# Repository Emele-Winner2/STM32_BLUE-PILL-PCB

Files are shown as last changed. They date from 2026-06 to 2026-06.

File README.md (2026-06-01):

# Custom STM32F103 "Blue Pill" Development Board 🚀

This repository contains the complete hardware design files for a custom, enhanced 4-layer redesign of the classic STM32F103 "Blue Pill" development board. Designed entirely in KiCad, this board optimizes signal integrity, power distribution, and clock stability compared to standard 2-layer commercial alternatives.

---

## 🛠️ Hardware Specifications & Features

* **MCU Core:** STM32F103C8T6 ARM Cortex-M3 microcontroller.
* **4-Layer Stackup:** Engineered with dedicated internal planes to maximize electromagnetic shielding and ensure pristine signal paths.
  * **Layer 1 (Top):** High-speed signaling (USB differential pairs), crystal oscillator tracking, and local component connections.
  * **Layer 2 (Internal):** Solid, unbroken **Ground (GND) Plane** for low-impedance return paths.
  * **Layer 3 (Internal):** **Power (PWR) Plane** for clean 5V power distribution.
  * **Layer 4 (Bottom):** General purpose I/O breakouts and non-critical low-speed routing.
* **USB Interface:** Native USB Full-Speed connection with hardware-matched series termination resistors and a proper 3.3V pull-up network for reliable host computer enumeration.
* **Dual Clock Architecture:** * High-Speed External (HSE): 8MHz main crystal with optimized, short symmetric routing.
  * Low-Speed External (LSE): 32.768kHz dedicated real-time clock (RTC) crystal.

---

## 📂 Repository Structure

```text
├── bluetooth_mcu.kicad_pro   # KiCad main project file
├── bluetooth_mcu.kicad_sch   # System schematic design
├── bluetooth_mcu.kicad_pcb   # 4-layer PCB layout design
└── README.md                 # Project documentation (this file)

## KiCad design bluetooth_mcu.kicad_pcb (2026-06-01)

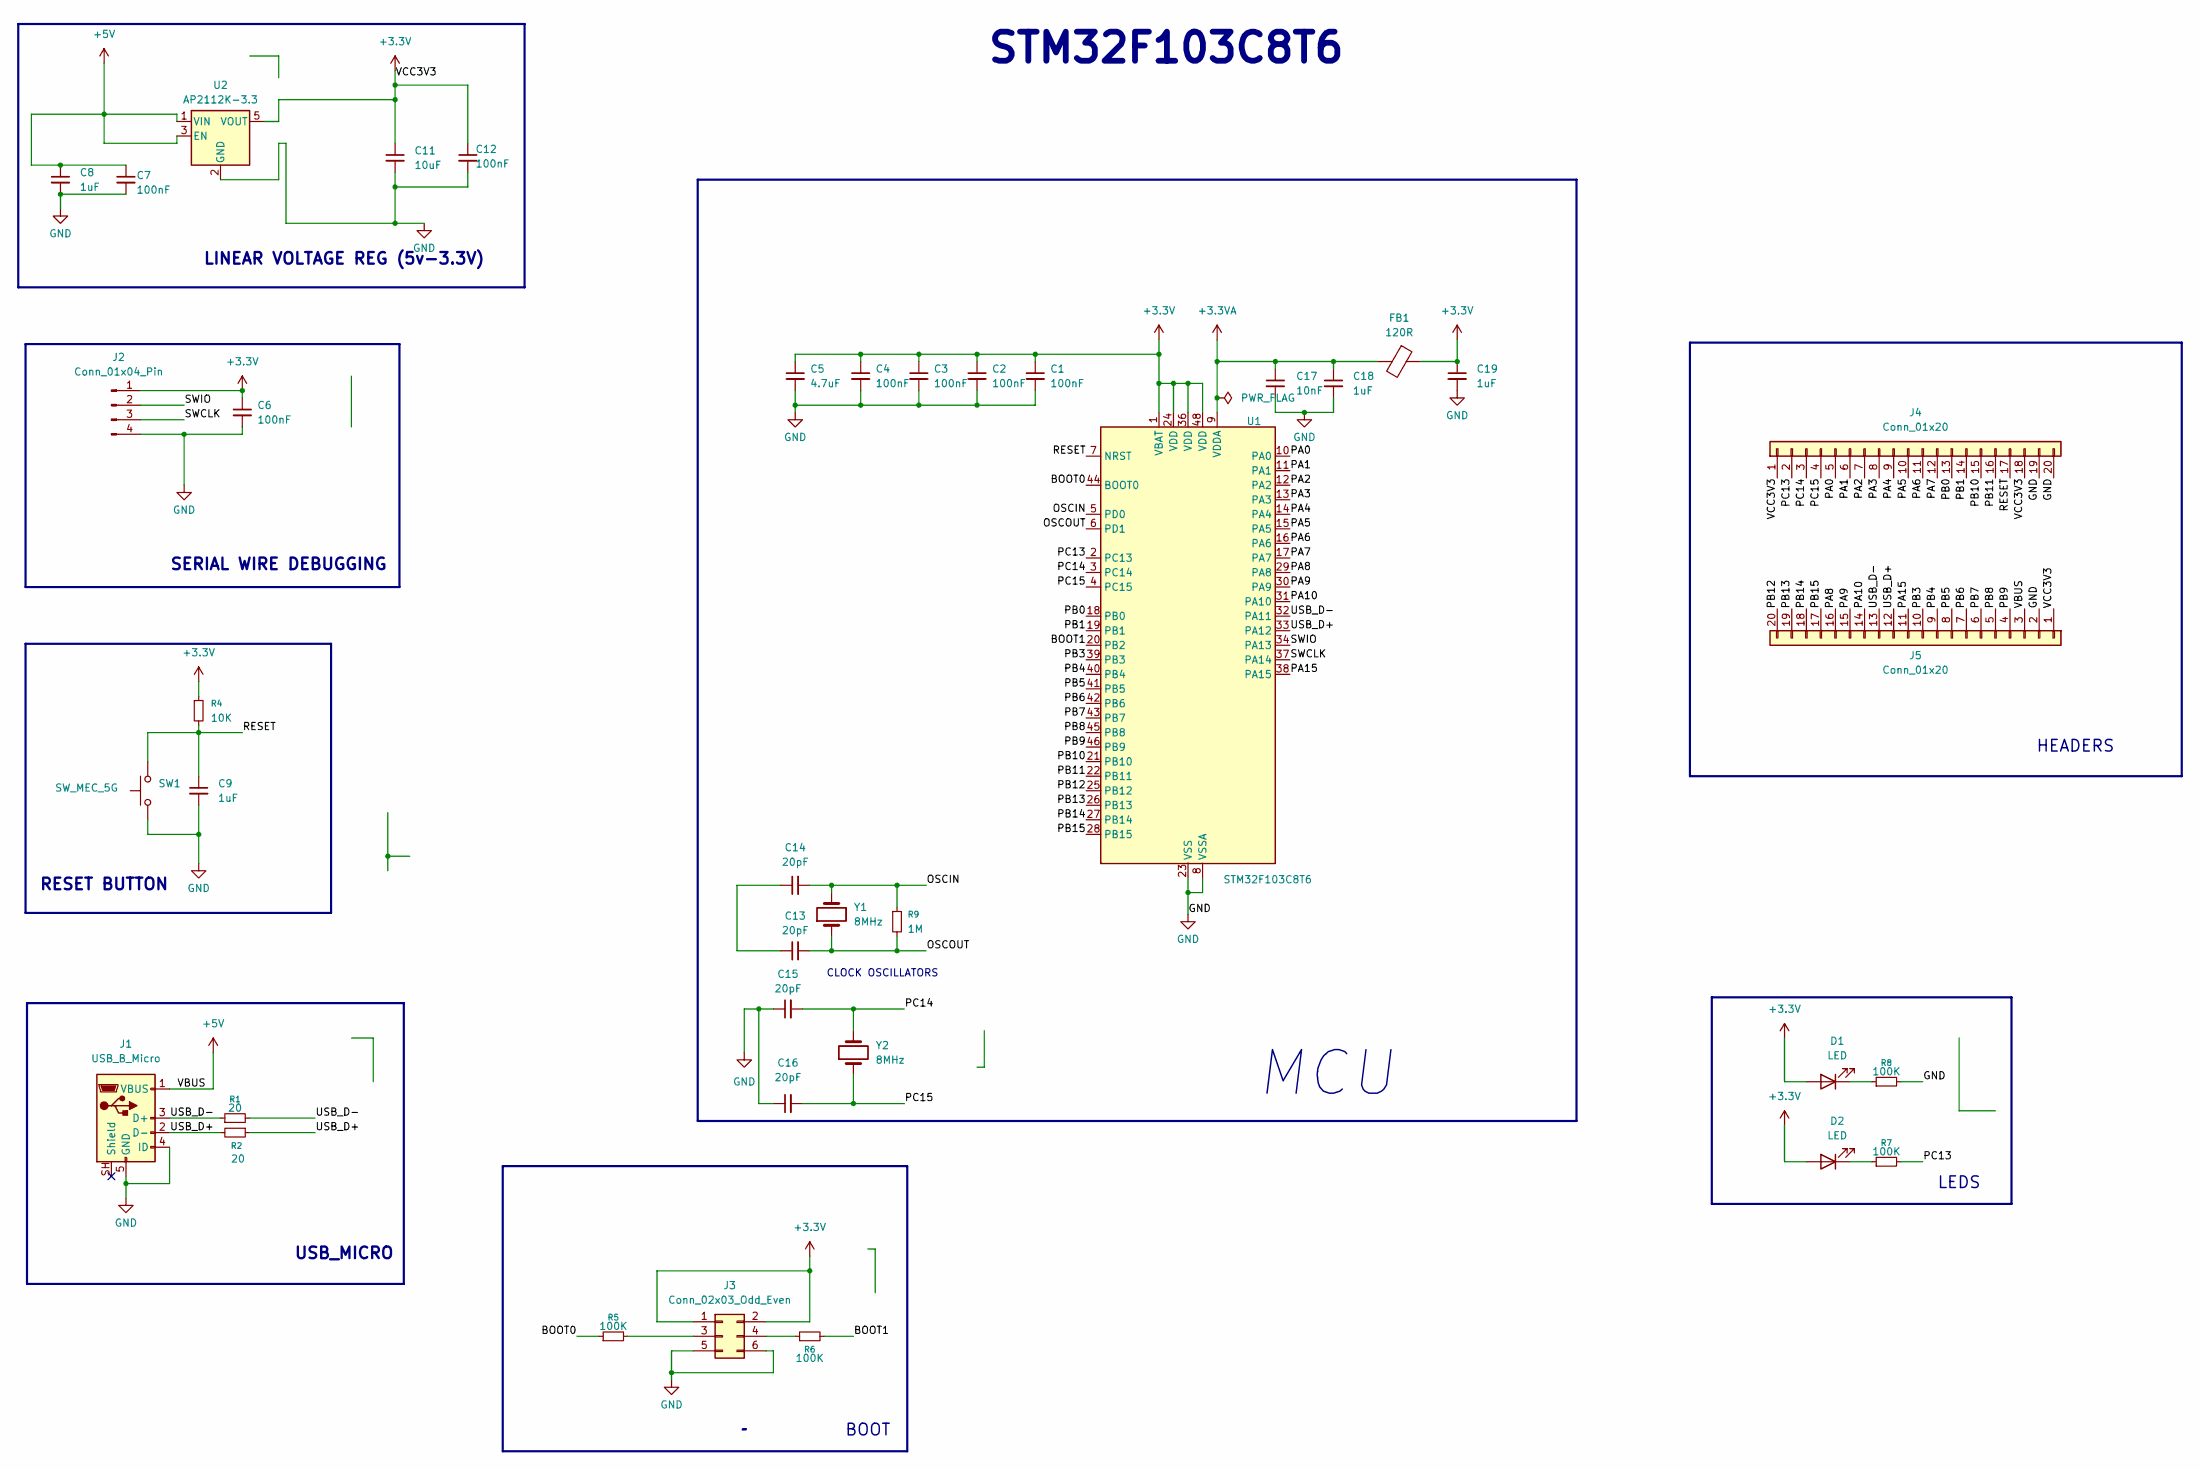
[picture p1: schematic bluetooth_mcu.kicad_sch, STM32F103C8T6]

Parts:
C1, C2, C3, C4, C6, C7, C12: 100nF; C_0603_1608Metric_Pad1.08x0.95mm_HandSolder
C5: 4.7uF; C_0603_1608Metric_Pad1.08x0.95mm_HandSolder
C8, C9, C18, C19: 1uF; C_0603_1608Metric_Pad1.08x0.95mm_HandSolder
C11: 10uF; C_0603_1608Metric_Pad1.08x0.95mm_HandSolder
C13, C14: 20pF; C_0402_1005Metric_Pad0.74x0.62mm_HandSolder
C15, C16: 20pF; C_0603_1608Metric_Pad1.08x0.95mm_HandSolder
C17: 10nF; C_0603_1608Metric_Pad1.08x0.95mm_HandSolder
D1, D2: LED; LED_0402_1005Metric_Pad0.77x0.64mm_HandSolder
FB1: 120R; R_0603_1608Metric
J1: USB_B_Micro; USB_Micro-B_Molex-105017-0001
J2: Conn_01x04_Pin; PinHeader_1x04_P2.54mm_Horizontal
J3: Conn_02x03_Odd_Even; PinHeader_2x03_P2.54mm_Vertical
J4, J5: Conn_01x20; PinHeader_1x20_P2.54mm_Vertical
R1, R2: 20; R_0603_1608Metric_Pad0.98x0.95mm_HandSolder
R4: 10K; R_0603_1608Metric_Pad0.98x0.95mm_HandSolder
R5, R6, R7, R8: 100K; R_0603_1608Metric_Pad0.98x0.95mm_HandSolder
R9: 1M; R_0603_1608Metric_Pad0.98x0.95mm_HandSolder
SW1: SW_MEC_5G; SW_PUSH_1P1T_6x3.5mm_H4.3_APEM_MJTP1243
U1: STM32F103C8T6; LQFP-48_7x7mm_P0.5mm
U2: AP2112K-3.3; SOT-23-5
Y1, Y2: 8MHz; Crystal_SMD_MicroCrystal_CC8V-T1A-2Pin_2.0x1.2mm_HandSolder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

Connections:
+3.3V: C1.1, C2.1, C3.1, C4.1, C5.1, C6.1, C11.1, C12.1, C19.1, D1.2 (A), D2.2 (A), FB1.1, J2.1, J3.1, J3.2, J4.1, J4.18, J5.1, R4.1, U1.1 (VBAT), U1.24 (VDD), U1.36 (VDD), U1.48 (VDD), U2.5 (VOUT)
+3.3VA: C17.1, C18.1, FB1.2, U1.9 (VDDA)
+5V: C7.1, C8.1, J1.1 (VBUS), J5.3, U2.1 (VIN), U2.3 (EN)
/BOOT0: R5.1, U1.44 (BOOT0)
/BOOT1: R6.2, U1.20 (PB2)
/OSCIN: C14.2, R9.1, U1.5 (PD0), Y1.2
/OSCOUT: C13.2, R9.2, U1.6 (PD1), Y1.1
/PA0: J4.5, U1.10 (PA0)
/PA1: J4.6, U1.11 (PA1)
/PA2: J4.7, U1.12 (PA2)
/PA3: J4.8, U1.13 (PA3)
/PA4: J4.9, U1.14 (PA4)
/PA5: J4.10, U1.15 (PA5)
/PA6: J4.11, U1.16 (PA6)
/PA7: J4.12, U1.17 (PA7)
/PA8: J5.16, U1.29 (PA8)
/PA9: J5.15, U1.30 (PA9)
/PA10: J5.14, U1.31 (PA10)
/PA15: J5.11, U1.38 (PA15)
/PB0: J4.13, U1.18 (PB0)
/PB1: J4.14, U1.19 (PB1)
/PB3: J5.10, U1.39 (PB3)
/PB4: J5.9, U1.40 (PB4)
/PB5: J5.8, U1.41 (PB5)
/PB6: J5.7, U1.42 (PB6)
/PB7: J5.6, U1.43 (PB7)
/PB8: J5.5, U1.45 (PB8)
/PB9: J5.4, U1.46 (PB9)
/PB10: J4.15, U1.21 (PB10)
/PB11: J4.16, U1.22 (PB11)
/PB12: J5.20, U1.25 (PB12)
/PB13: J5.19, U1.26 (PB13)
/PB14: J5.18, U1.27 (PB14)
/PB15: J5.17, U1.28 (PB15)
/PC13: J4.2, R7.2, U1.2 (PC13)
/PC14: C15.2, J4.3, U1.3 (PC14), Y2.2
/PC15: C16.2, J4.4, U1.4 (PC15), Y2.1
/SWCLK: J2.3, U1.37 (PA14)
/SWIO: J2.2, U1.34 (PA13)
/USB_D+: J1.2 (D-), J5.12, R2.1, R2.2, U1.33 (PA12)
/USB_D-: J1.3 (D+), J5.13, R1.1, R1.2, U1.32 (PA11)
unnamed: C13.1, C14.1
unnamed: D1.1 (K), R8.1
unnamed: D2.1 (K), R7.1
unnamed: J3.3, R5.2
unnamed: J3.4, R6.1

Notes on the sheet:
USB_MICRO
STM32F103C8T6
SERIAL WIRE DEBUGGING
BOOT
LINEAR VOLTAGE REG (5v-3.3V)
CLOCK OSCILLATORS
RESET BUTTON
MCU
HEADERS
LEDS

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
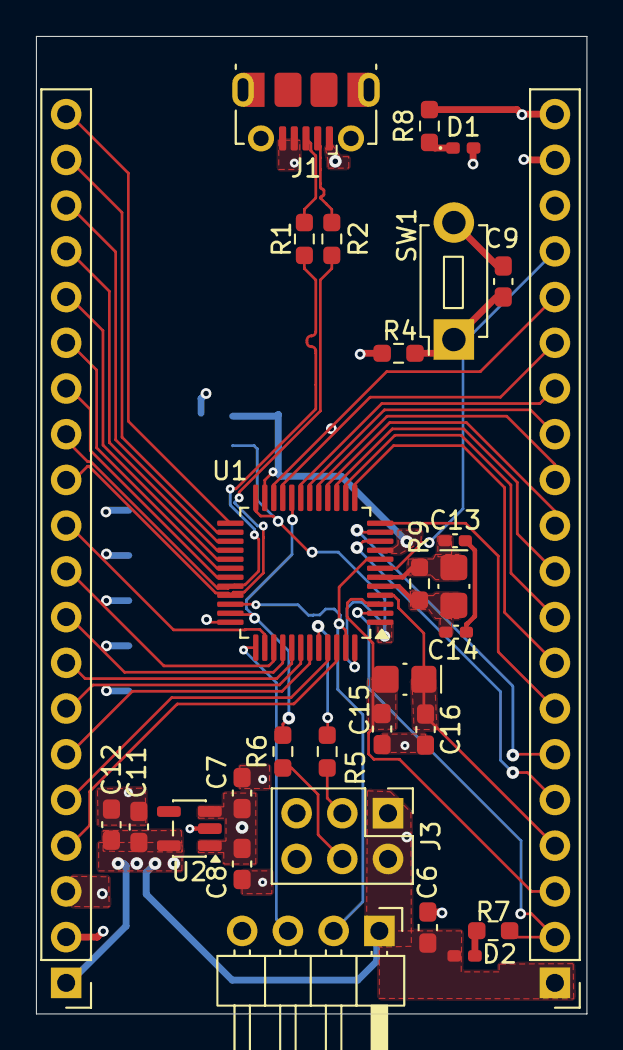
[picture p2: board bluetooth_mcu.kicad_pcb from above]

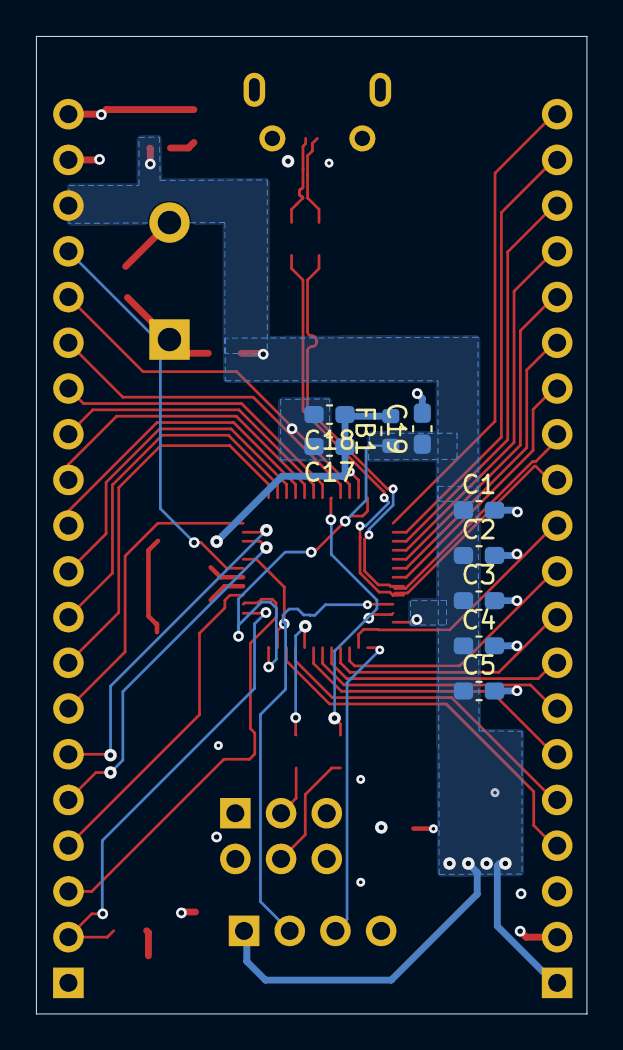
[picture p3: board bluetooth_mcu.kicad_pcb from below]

Board: 4 copper layers, 30.6 x 54.3 mm, 39 parts (9 on the bottom side), 48 nets.

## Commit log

2026-06-01 Update README with project details and specifications
    Added detailed project information and specifications for the custom STM32F103 'Blue Pill' development board, including hardware features and repository structure.
2026-06-01 Added files to repo
    [bluetooth_mcu.kicad_pcb, bluetooth_mcu.kicad_sch]
